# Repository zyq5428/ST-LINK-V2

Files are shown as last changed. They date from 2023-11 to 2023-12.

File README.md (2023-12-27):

# ST-LINK-V2
依据参考资料制作ST-LINK-V2，并实践一些Allegro技巧。

## 初衷

* 自己做一些ST-LINK便于后期自己调试STM32芯片
* 扩展一些UART，I2C，GPIO接口出来，其他时候作为一个STM32F103开发板用
* 重新熟悉下Allegro软件，并实践一些新版本的技巧
* 自己根据需要，亲自做里面用到的所有器件的封装和3D

## 产品效果图

### Nucleo版本

* 正面

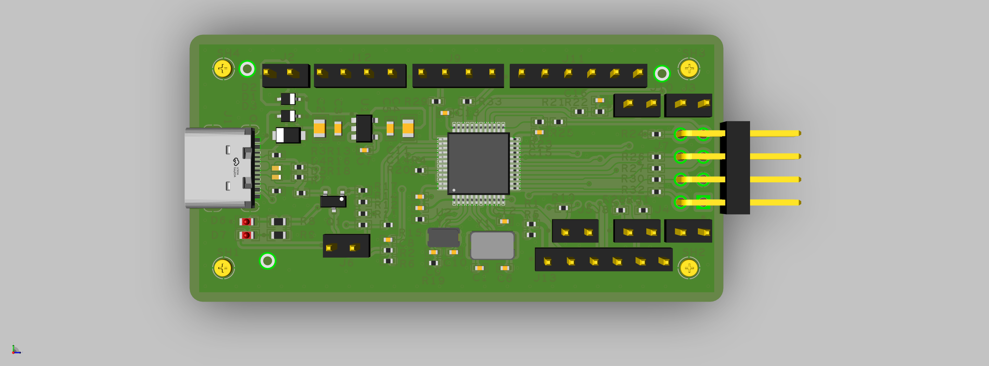
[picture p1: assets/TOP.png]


* 背面

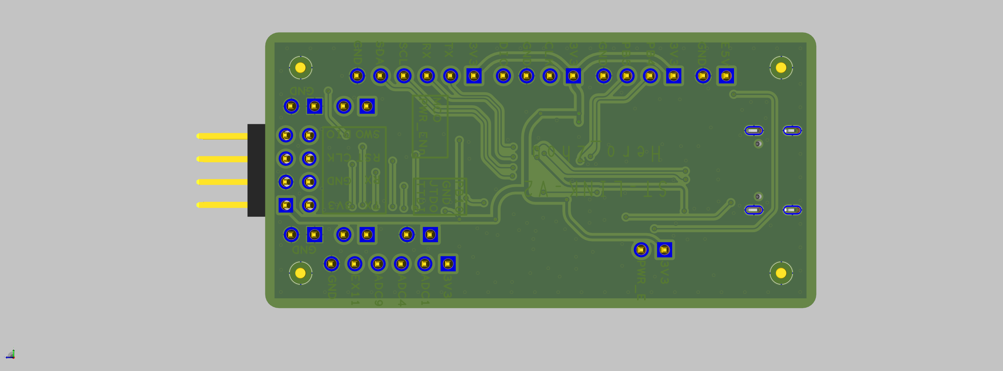
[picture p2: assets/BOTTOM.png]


* 为了方便以后可能用加热台自己贴片，所以尽量将元器件布置在同一面
* 为了最大化降低成本，采用双层板设计，但依旧尽力保证设计规范和美观

## 回板焊接

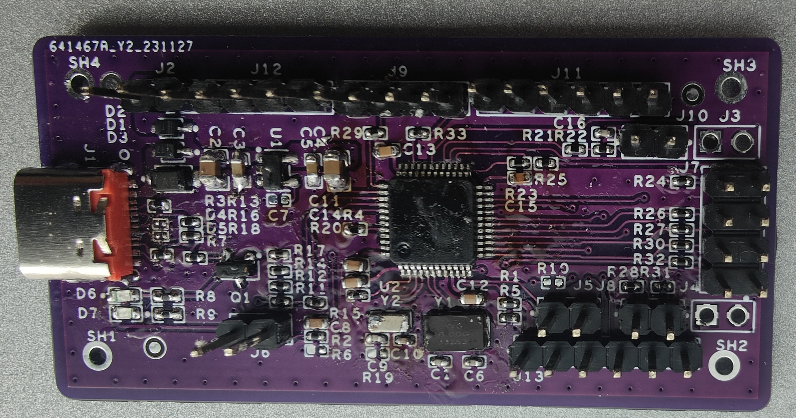
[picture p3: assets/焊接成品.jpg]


### 优化版

* 在Nucleo版本上进行了一些优化，去除了不必要的东西，然后按照自己的想法进行了一些接口的预留

* 正面

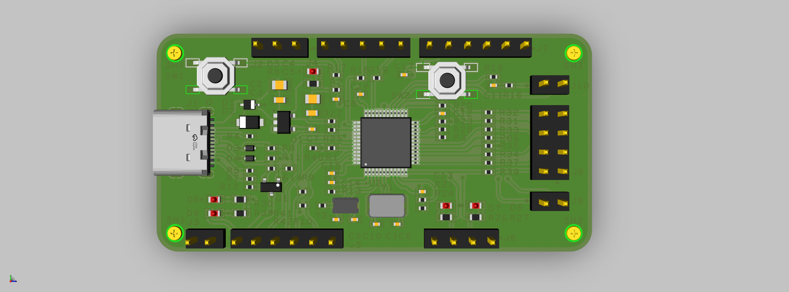
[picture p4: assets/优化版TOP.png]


* 背面

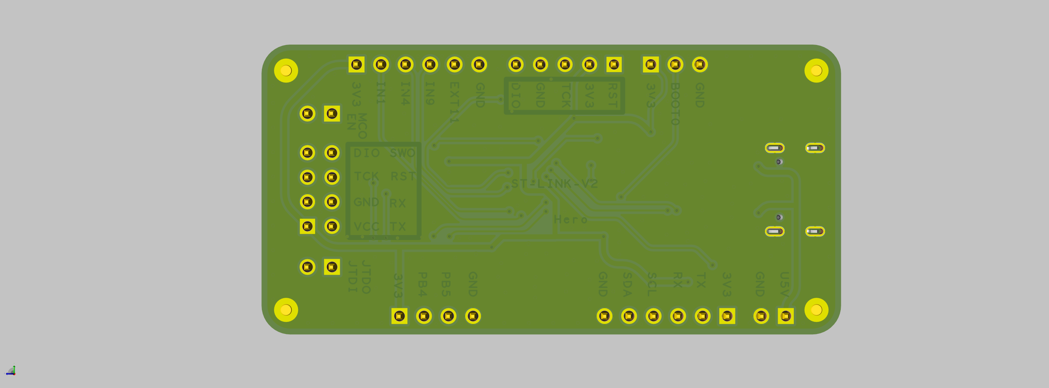
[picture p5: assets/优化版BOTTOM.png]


* 拼板效果图

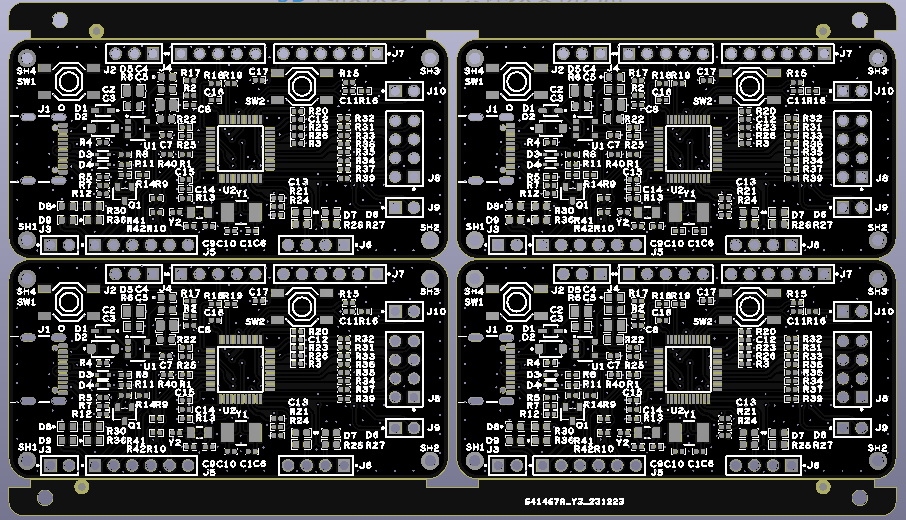
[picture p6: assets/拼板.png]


* PCB回板

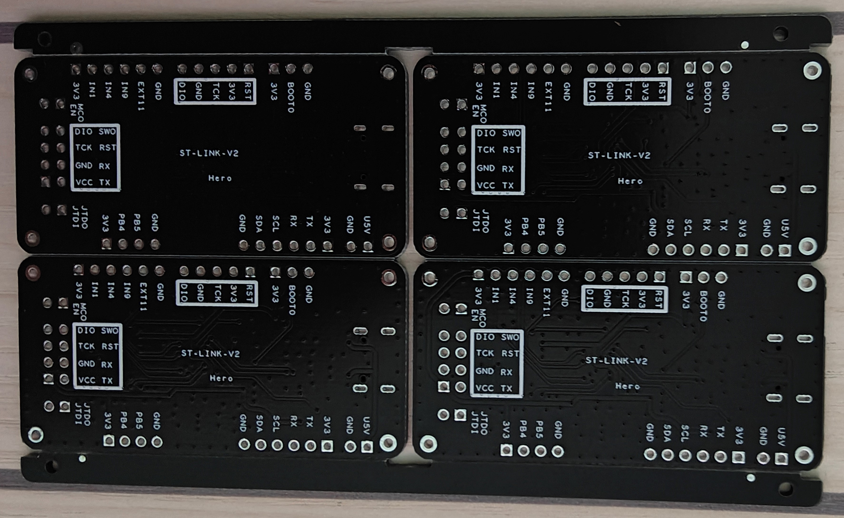
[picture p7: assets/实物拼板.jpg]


* 成品

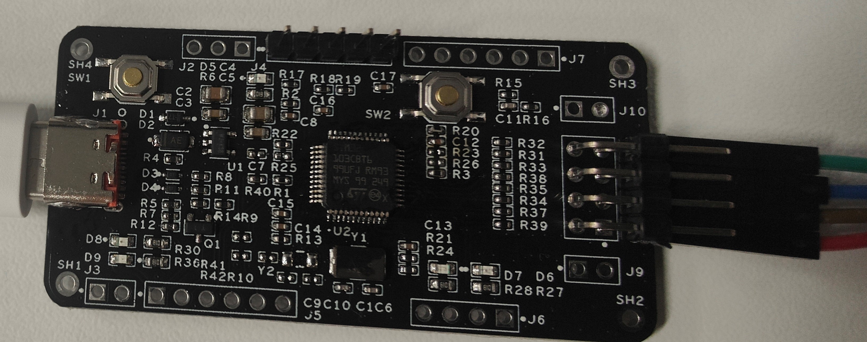
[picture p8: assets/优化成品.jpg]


## 原理介绍

借鉴于：https://oshwhub.com/CYIIOT/ST_LINK-V2_1

### 简介

* ST-Link的硬件，官方推出了三大版本：V1、V2和V3。在官方《TN1235 ST-LINK衍生产品概述》中有详细的说明。
* ST-Link/V2：支持STM32和STM8调试，不带虚拟串口，TB上卖的大多是这种，目前手头还有好几个这个版本的ST-Link。后面会使用这个版本进行烧录。
* ST-Link/V2-1：支持STM32调试，带虚拟串口和虚拟U盘下载，目前ST官方的Nucleo系列评估板上面板载的ST-Link就是这个版本。
* 潘多拉开发板上的ST-link V2-1 出厂主控使用的是FLASH 容量为64K的STM32F103C8T6，但是ST-link V2-1最新的固件已经超过了64K，芯片容量不足。 因此本项目主控选择的是FLASH容量为128KB的STM32F103CBT6（商品编号：C8304），这是C8T6的大容量版本，可以直接PIN to PIN 替换。也可以使用合宙通信推出的AIR32F103CBT6，有伙伴测试是OK的。
  * AIR32F103CBT6参考链接：[AIR32F103芯片 - LuatOS 文档](https://wiki.luatos.com/chips/air32f103/mcu.html)

### 版本检测和处理

* All ST-Link variants:
    * PC13/14 open -> Standalone ST-Link v2 or baite, some STM32 Disco w/o accessible UART RX/TX
    * PC13 low -> SWIM internal connection
    * PC13/PC14 both low -> ST-Link v2 on some F4_Diso boards.

### USB 枚举

* USB设备的电流是设备接入计算机的时候，枚举的过程中向计算机申请的，有一个8位寄存器，值范围是0~24，对应的电流是20mA~500mA。如果枚举过程中设备没有向计算机提交这个需要电流的值，计算机则默认按最大电流提供，USB2.0设备是500mA，USB1.1设备是200mA。

* 标准下行端口（SDP）
    * 这种端口的D+和D-线上具有15kΩ下拉电阻。限流值为：挂起时2.5mA，连接时为100mA，连接并配置为较高功率时为500mA。

* 根据USB协议，工作在主机模式，USB DP/DM下拉到GND，工作在设备模式，上拉到VCC（DP上拉表示高全速设备，DM上拉表示低速设备，STM32在Device模式只支持高速或全速）。
    * STM32F103的USB是全速的从设备，所以D+上需要一个1.5K的上拉电阻。建议用一个IO口控制这个上拉电阻，因为插入USB主机时，如果直接接这个上拉电阻，USB主机会直接枚举设备，如果STM32F103没有准备好则可能识别错误。如果用GPIO控制，可以保证STM32F103已经准备好了再枚举设备。

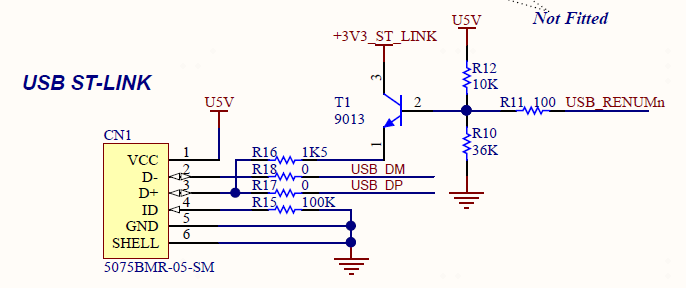
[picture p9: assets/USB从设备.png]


### 32.768KHz晶振

* 我的板子上预留了一个小封装的32.768KHz晶振，方便后期改为通用开发板功能。

### 电源

* 当ST-LINK的USB供电时：
    * ST-LINK使用一个3.3V 150mA LDO进行供电，供电电源为+3V3_ST_LINK。
    * 在USB枚举之前，只有ST-LINK部分供电，因为主机PC只能提供100mA电流。在USB枚举过程中，Nculeo板向主机PC请求300mA电流，如果主机可提供所需电流，则通过PWR_ENn拉低打开U5V供电MOS，这时目标MCU的3.3V LDO会输出3.3V电压，目标板开始供电。如果请求失败，则不打开U5V供电MOS。
    * PWR_EXT(PB3)作用：
        * 如果接ST_LINK的3.3V供电电源，则允许最大电流100mA，使用U5V供电的话，要连接,可以选择4.7K上拉；
        * 如果浮空，则允许最大电流300mA；

* E5V是外部7-12V的供电，通过一个5.0V 800mA的 LDO进行供电。

* AIN_1功能:
    * ST-LINK在烧录时，通过PWR_ENn拉低打开U5V供电MOS，这时目标MCU的3.3V LDO会输出3.3V电压。
    * AIN_1引脚通过上下各4.7K的分压电阻，判断MCU供电是否正常，如果只是做ST_LINK功能，直接接ST_LINK的3.3V供电电源。

### BOOT启动配置



* 一般来说就是指我们下好程序后，重启芯片时，SYSCLK的第4个上升沿，BOOT引脚的值将被锁存。用户可以通过设置BOOT1和BOOT0引脚的状态，来选择在复位后的启动模式。
    * 1、第一种方式(boot0 = 0)：Flash memory启动方式，启动地址：0x08000000 是STM32内置的Flash，一般我们使用JTAG或者SWD模式下载程序时，就是下载到这个里面，重启后也直接从这启动程序。基本上都是采用这种模式。
    * 2、第二种方式(boot0 = 1；boot1 = 0)：System memory启动方式，启动地址：0x1FFF0000从系统存储器启动，这种模式启动的程序功能是由厂家设置的。一般来说，这种启动方式用的比较少。系统存储器是芯片内部一块特定的区域，STM32在出厂时，由ST在这个区域内部预置了一段BootLoader， 也就是我们常说的ISP程序， 这是一块ROM，出厂后无法修改。一般来说，我们选用这种启动模式时，是为了从串口下载程序，因为在厂家提供的BootLoader 中，提供了串口下载程序的固件，可以通过这个BootLoader将程序下载到系统的Flash中。但是这个下载方式需要以下步骤：
        * 1、将BOOT0设置为1，BOOT1设置为0，然后按下复位键，这样才能从系统存储器启动BootLoader
        * 2、最后在BootLoader的帮助下，通过串口下载程序到Flash中
        * 3、程序下载完成后，又有需要将BOOT0设置为GND，手动复位，这样，STM32才可以从Flash中启动可以看到， 利用串口下载程序还是比较的麻烦，需要跳帽跳来跳去的，非常的不注重用户体验。
    * 3、第三种方式(boot0 = 1;boot1 = 1)：SRAM启动方式。，启动地址：0x20000000 内置SRAM，既然是SRAM，自然也就没有程序存储的能力了，这个模式一般用于程序调试。假如我只修改了代码中一个小小的 地方，然后就需要重新擦除整个Flash，比较的费时，可以考虑从这个模式启动代码（也就是STM32的内存中），用于快速的程序调试，等程序调试完成后，在将程序下载到SRAM中。
* 关于启动地址，理论上，CM3中规定上电后CPU是从0地址开始执行，但是这里中断向量表却被烧写在0x0800 0000地址里(Flash memory启动方式)，那启动时不就找不到中断向量表了？既然CM3定下的规矩是从0地址启动，SMT32当然不能破坏ARM定下的“规矩”，所以它做了一个启动映射的过程，就是和芯片上总能见到的BOOT0和BOOT1有关了，当选择从主Flash启动模式后，芯片一上电，Flash的0x0800 0000地址被映射到0地址处，不影响CM3内核的读取，所以这时的CM3既可以在0地址处访问中断向量表，也可以在0x0800 0000地址处访问中断向量表，而代码还是在0x0800 0000地址处存储的。
* 关于flash死锁的解决办法(Flash memory启动方式)，开发调试过程中，由于某种原因导致内部Flash锁死，无法连接SWD以及JTAG调试，无法读到设备，可以通过修改BOOT模式重新刷写代码。修改为BOOT0=1，BOOT1=0即可从系统存储器启动，ST出厂时自带Bootloader程序，SWD以及JTAG调试接口都是专用的。重新烧写程序后，可将BOOT模式重新更换到BOOT0=0，BOOT1=X即可正常使用。

* 我们可以通过10K或100K电阻接VCC或者GND，建议BOOT1接地，BOOT0预留一个3 Pin端子，以防后期芯片flash锁死了。

### PB10作用

* 暂时没搞懂，我看别人不接和接VCC，VDD都没有影响。

### COM指示灯

* 在ST官方的ST-Link V2.1图纸中有一个名为COM的指示灯,这是一个红绿双色的LED指示灯，就是下图所示的这个LED。

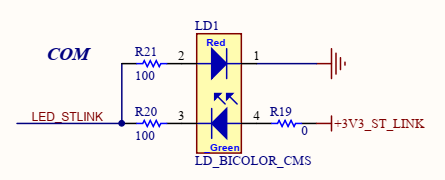
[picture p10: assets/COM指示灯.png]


* 那么这个指示灯有什么作用呢，在官方的TN1235技术手册中有专门的介绍，截取相关部分如下：

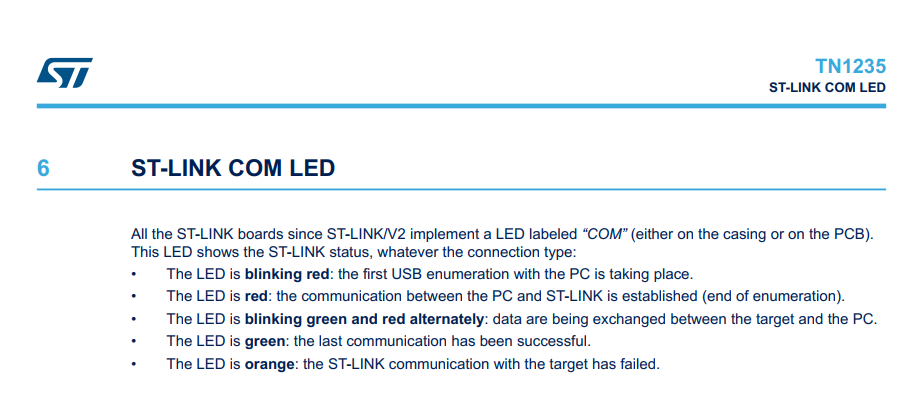
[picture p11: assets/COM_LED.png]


* 自ST-LINK/V2起，所有ST-LINK板均带有一个标有“COM”的LED（在外壳或PCB上）。无论连接类型如何，此LED都会显示ST-LINK状态：
    * LED呈红色闪烁：正在与PC进行第一个USB枚举。
    * LED为红色：PC与ST-LINK之间的通信已建立（枚举结束）。
    * LED呈绿色和红色交替闪烁：正在目标和PC之间交换数据。
    * LED为绿色：上一次通信已成功。
    * LED为橙色：与目标的ST-LINK通信失败

## 烧录固件

### 固件版本

* 由于官方没有将ST-Link里面源码公开，同时也没有直接给出ST-Link固件（读保护），但是目前（2020年7月）网上已有流传多个版本的固件。
    * 版本一：STLink V2.J16.S4版本固件：标准V2版本，支持SWD和SWIM接口，这个版本的固件是。
    * 版本二：STLink V2.J28.M18版本固件：是用于ST-LINK/V2-1、ST-LINK/V2-A、ST-LINK/V2-B板(具有STM32调试接口、大容量存储接口、虚拟COM端口)的版本。
    * 本项目制作ST-Link V2-1 必须使用V2.J28.M18这个版本作为烧录的固件版本。

### 烧录工具

* 第一次烧录固件可使用这两个工具：
    * STM32CubeProg
    * STM32 ST-LINK Utility
* 本次烧录使用STM32 ST-LINK Utility，STM32 ST-LINK Utility的功能比STM32CubeProg要稍微简单一些，其主要功能也是编程（下载）。烧录截图如下，操作很简单，大概看一下就知道了:

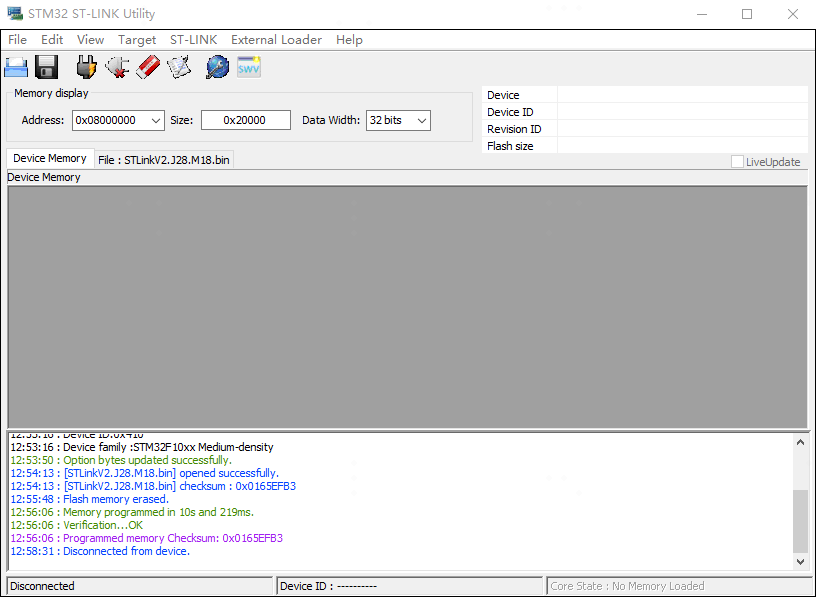
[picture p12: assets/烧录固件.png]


### 升级ST-LINK

* 固件更新有三种方法：
    * 官方固件升级应用程序ST-LinkUpgrade
    * 使用STM32CubeProg或者STM32 ST-LINK utility自带的升级工具升级
    * 使用Keil MDK-ARM 内置的升级工具进行升级，当ST-link 的版本低于MDK内置的版本时，会提示进行升级。Keil MDK-ARM v5.31内置固件升级版本与STM32CubeProg V2.4.0 内置固件升级版本是一样的。
* 本次升级使用ST-LinkUpgrade，升级截图如下：

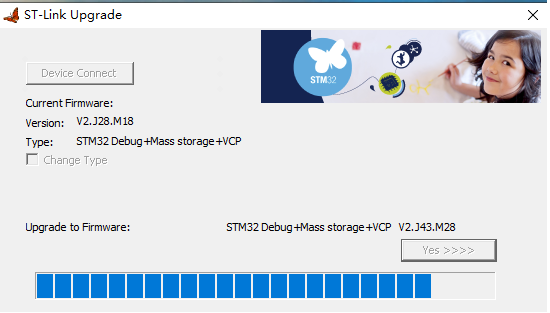
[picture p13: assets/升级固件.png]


* 至此，ST-LINK的制作就完成了。

## 注意事项

* ST-LINK 固件升级工具不知从哪个版本开始，不支持跨版本更新固件。
* ST-LINK 最近的几个版本的固件已加入了读保护，SWD口是锁上的，所以不能通过SWD口读写固件。
    * 如果想改为其他的，我们可以用STM32 ST-LINK utility将写保护的级别修改。菜单栏target里打开Option Bytes...选项，或者直接通过快捷键ctrl+B打开，请确保当前已经正确连接了stlink和目标板，否则会出现报错。
    * 关键点：将Read Out Protection选项设置为disable，点击Apply，这时候Flash已经成功解锁了。但是同时发现，内部Flash已经被擦除了；这可能STM32的保护机制有关，防止程序被拷机，然后进行反编译破解，这样也可以提高破解的门槛。
    * 完成以上步骤之后，在菜单栏Target下选择Disconnect，或者通过快捷键ctrl+D断开和目标板的连接；重新进入MDK，就能正常对目标板进行调试，仿真，以及程序的烧写。

正确连接的情况下，打开Option Bytes...，发现在这里Read Out Protection选项是enable，这个表示无法通过swd读取STM32内部Flash的程序。
    
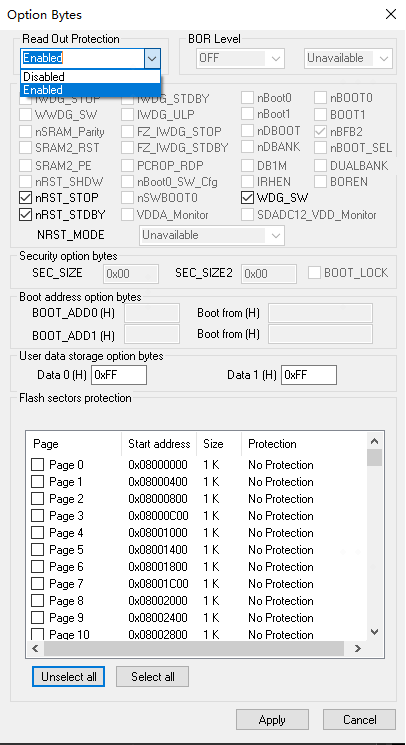
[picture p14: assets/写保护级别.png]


* 如果想改成DAP-LINK 之类的固件，不能通过SWD口烧录固件，但是可以通过ISP的方式擦除STM32的固件信息，然后就可以使用SWD口正常读写。
    * USB转串口连接线烧写（又称ISP烧写，且使用的串口必须是串口1）:
        * Step1:将BOOT0设置为1，BOOT1设置为0，然后按下复位键，这样才能从系统存储器启动BootLoader;
        * Step2:最后在BootLoader的帮助下，通过串口下载程序到Flash中;
        * Step3:程序下载完成后，必须要将BOOT0设置为GND，手动复位，这样，STM32才可以从Flash中启动。

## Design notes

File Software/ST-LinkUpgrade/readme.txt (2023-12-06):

STLink firmware upgrade applications

1. In folder Windows:

   Contains the application in its "historical" form: executable dedicated to Windows + dll.
   With all most recent firmwares (V1J13S3 for ST-Link/V1 boards, V2J43S7 for ST-Link/V2 boards,
   V2J43M28 for ST-Link/V2-1 boards, V3J13M4 for STLINK-V3 boards, V4J3B1P4 for STLINK-V3PWR)

2. In folder AllPlatforms:

   Contains a new GUI based on Java, with native ST-Link libraries for running on Windows 32 bits,
   Windows 64bits, Linux 32bits, Linux 64bits and MacOS 64bits.
   
   The application requires the Java Runtime Environment 7u51 (or more recent) being installed.
   In platforms without .jar file extension association, the application can be launch by the command
   "java -jar STLinkUpgrade.jar".

   On Linux, the application relies on libusb-1.0, which must be installed separately. For
   instance on Ubuntu, through the command "sudo apt-get install libusb-1.0".

   On Linux, users must be granted with rights for accessing the ST-Link USB devices. To do
   that, it might be necessary to add rules into /etc/udev/rules.d. This can be achieved by
   running one of the package provided into the subdirectory StlinkRulesFilesForLinux.

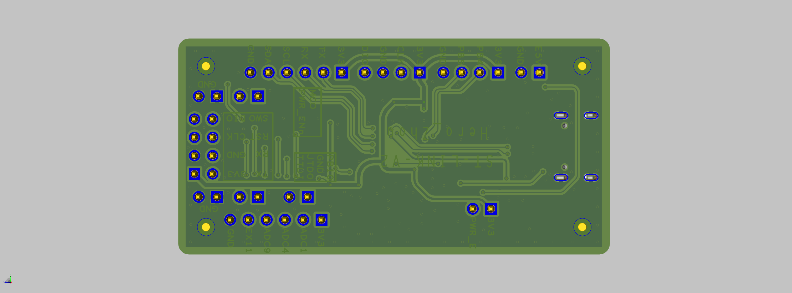
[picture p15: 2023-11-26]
Hardware/Original/allegro/ASM/BOTTOM.png

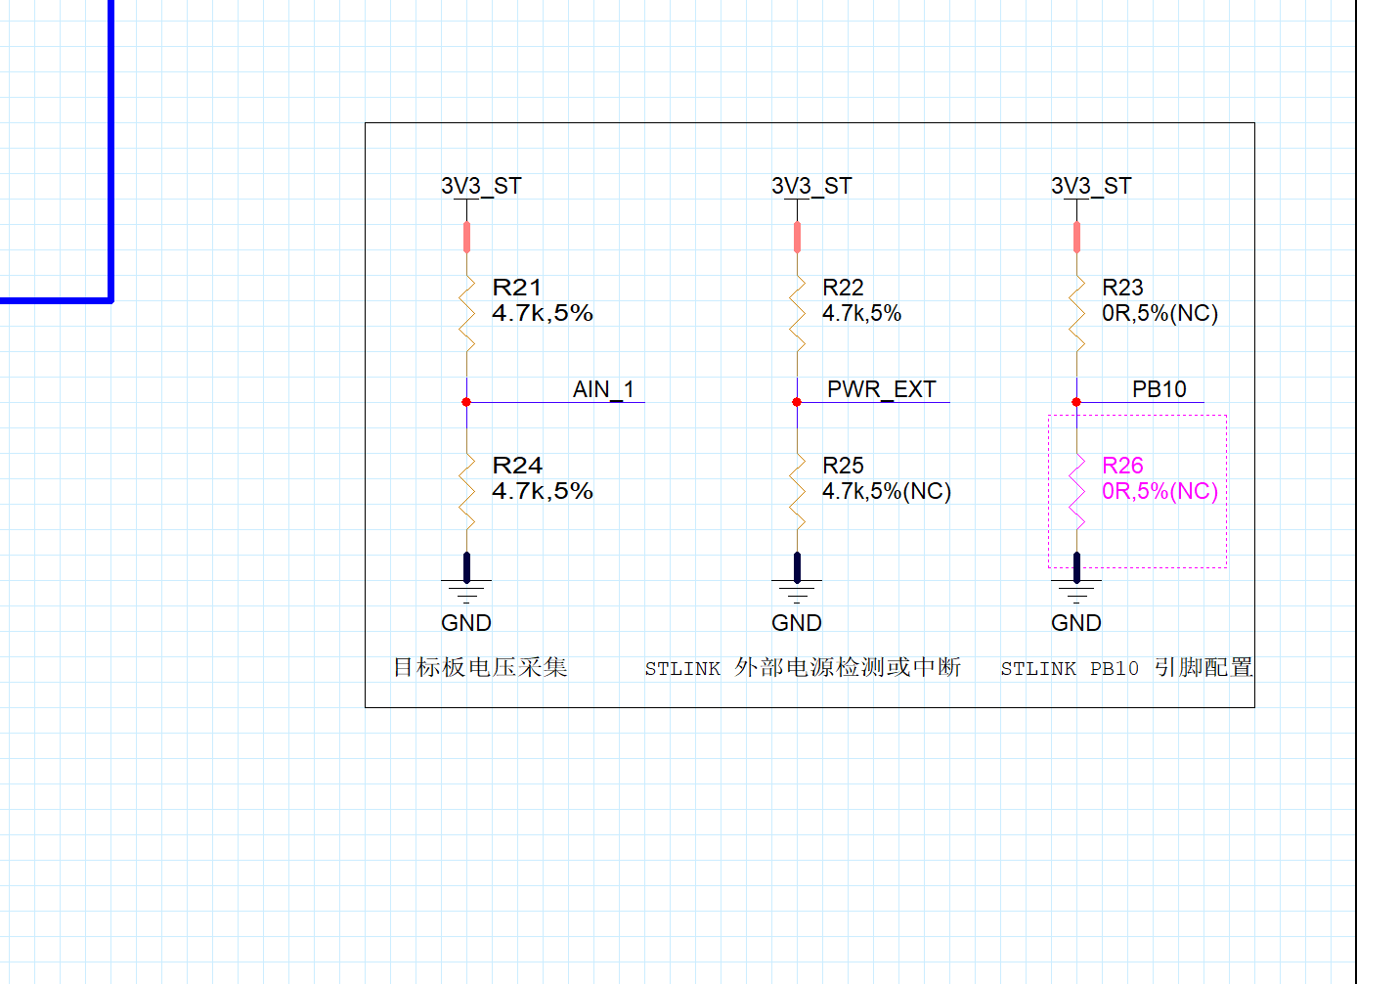
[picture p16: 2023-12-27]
Hardware/Optimize/ST-LINK-V2_PRO_OPT.png

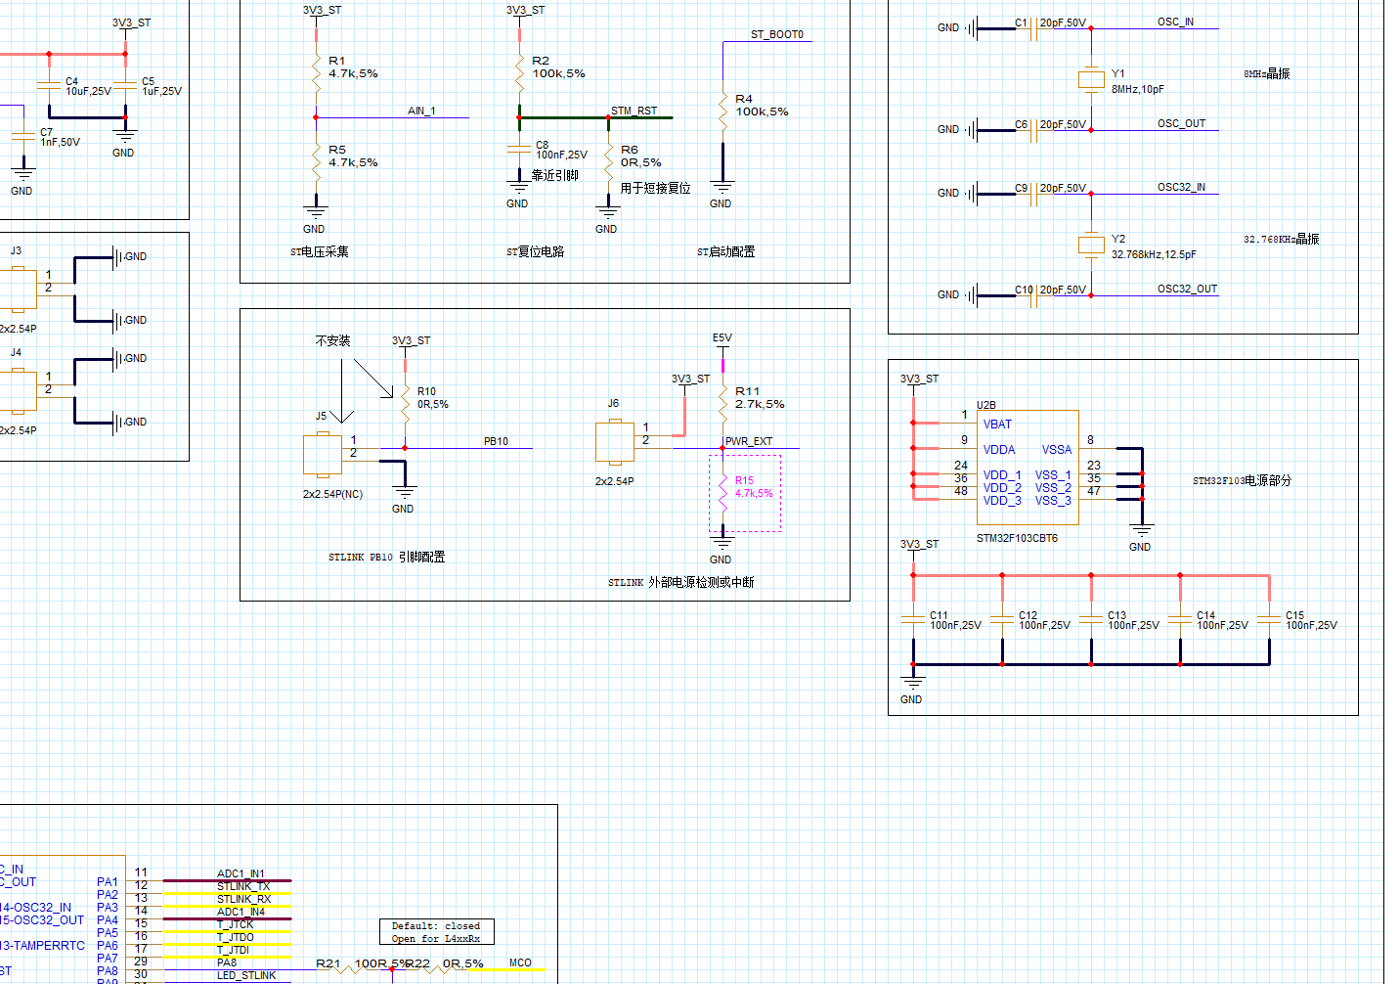
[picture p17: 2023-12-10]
Hardware/Original/ST-LINK-V2_PRO.png

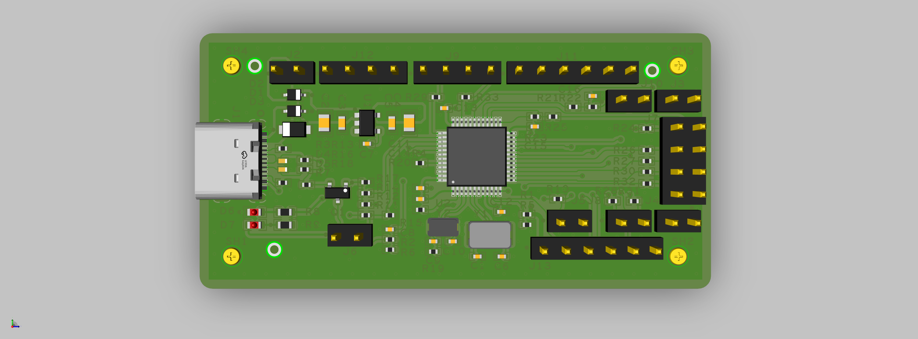
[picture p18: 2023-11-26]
Hardware/Original/allegro/ASM/TOP.png

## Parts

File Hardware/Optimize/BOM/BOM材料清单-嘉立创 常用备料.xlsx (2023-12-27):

xxxx项目物料清单
型号 | 封装 | 参数/规格 | 品牌 | 分类 | 单套用量 | 商品编号
 | C0402 | 100nF,25V |  | 贴片电容 | 100 | C56392 | 0
 | SOD-523 | TVSS5VCES-02GP-J |  | 静电放电(ESD)保护器件 | 50 | C5199217
 | LED0603 | Red_LED |  | 发光二极管/LED | 50 | C84263 | 20
 | LED0603 | Green_LED |  | 发光二极管/LED | 50 | C84267 | 20
 | LED0603 | Blue_LED |  | 发光二极管/LED | 50 | C84266 | 20
 | USB-C-SMD-16P | TYPE-C-16P |  | USB连接器 | 20 | C2997434 | 5
 | R0402 | 0R,5% |  | 贴片电阻 | 300 | C17168 | 100
 | SW_SMD_4P_5D1x5D1 | TS-1187A-B-A-B |  | 轻触开关 | 50 | C318884
 | SOT23-5 | RT9013-33GB |  | 线性稳压器(LDO) | 20 | C587158 | 5
 | LQFP48 | STM32F103CBT6 |  | 单片机 | 2 | C8304 | 5
 | SMD5032-2P | 8MHz,10pF |  | 无源晶振 | 20 | C115962 | 5
 | SMD3215-2P | 32.768kHz,12.5pF |  | 无源晶振 | 10 | C620155 | 5
 | SOT-23-5 | PJ4054B |  | 电池管理 | 20 | C2911335
 | SOP-8 | CH340N |  | USB芯片 | 20 | C2977777
 | 插件,D=9mm | HNB09A05 |  | 蜂鸣器 | 20 | C96493

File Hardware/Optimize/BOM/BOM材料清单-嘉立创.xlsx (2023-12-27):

xxxx项目物料清单
型号 | 封装 | 参数/规格 | 品牌 | 分类 | 单套用量 | 商品编号
 | C0402 | 20pF,50V |  | 贴片电容 | 5 | C1554 | 100
 | C0805 | 10uF,25V |  | 贴片电容 | 2 | C15850 | 50
 | C0603 | 1uF,25V |  | 贴片电容 | 2 | C15849 | 100
 | C0402 | 100nF,25V |  | 贴片电容 | 7 | C56392 | 0
 | C0402 | 1N4007WS |  | 通用二极管 | 1 | C7473299 | 50
 | SOD-323 | SMF5.0A |  | 瞬态抑制二极管(TVS) | 1 | C908213 | 20
 | SOD-523 | TVSS5VCES-02GP-J |  | 静电放电(ESD)保护器件 | 2 | C5199217
 | LED0603 | Red_LED |  | 发光二极管/LED | 3 | C84263 | 20
 | LED0603 | Green_LED |  | 发光二极管/LED | 2 | C84267 | 20
 | USB-C-SMD-16P | TYPE-C-16P |  | USB连接器 | 1 | C2997434 | 5
 | HEADER_4X2_2P54 | 4x2.54P |  | 排针 | 1 | C492429 | 5
 | HEADER_6X1_2P54 | 6x2.54P |  | 排针 | 1 | C2895846 | 5
 | SOT-23 | SS8050 |  | 三极管(BJT) | 1 | C2150 | 50
 | R0402 | 100k,5% |  | 贴片电阻 | 2 | C25741 | 100
 | R0402 | 0R,5% |  | 贴片电阻 | 16 | C17168 | 100
 | R0402 | 5.1k,5% |  | 贴片电阻 | 2 | C25905 | 100
 | R0603 | 1k,5% |  | 贴片电阻 | 5 | C21190 | 100
 | R0402 | 10k,5% |  | 贴片电阻 | 2 | C60490 | 100
 | R0402 | 100R,5% |  | 贴片电阻 | 3 | C25076 | 100
 | R0402 | 36k,5% |  | 贴片电阻 | 1 | C43676 | 100
 | R0402 | 1.5k,5% |  | 贴片电阻 | 1 | C25867 | 100
 | R0402 | 4.7k,5% |  | 贴片电阻 | 3 | C25900 | 100
 | SW_SMD_4P_5D1x5D1 | TS-1187A-B-A-B |  | 轻触开关 | 2 | C318884
 | SOT23-5 | RT9013-33GB |  | 线性稳压器(LDO) | 1 | C587158 | 5
 | LQFP48 | STM32F103CBT6 |  | 单片机 | 1 | C8304 | 5
 | SMD5032-2P | 8MHz,10pF |  | 无源晶振 | 1 | C115962 | 5
 | SMD3215-2P | 32.768kHz,12.5pF |  | 无源晶振 | 1 | C620155 | 5

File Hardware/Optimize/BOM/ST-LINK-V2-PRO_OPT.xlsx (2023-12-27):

Item | Quantity | Reference | Part | PCB Footprint
1 | 5 | C1,C6,C9,C10,C11 | 20pF,50V | CAPC100X50X55L25N
2 | 2 | C2,C4 | 10uF,25V | CAPC200X125X145L45N
3 | 2 | C3,C5 | 1uF,25V | CAPC160X80X90L30N
5 | 7 | C8,C12,C13,C14,C15,C16,C17 | 100nF,25V | CAPC100X50X55L25N
6 | 1 | D1 | 1N4007WS | SOD265X130X110L32X32N
7 | 1 | D2 | SMF5.0A | SODFL370X180X135L60_50X100N
8 | 2 | D3,D4 | TVSS5VCES-02GP-J | SODFL160X80X70L20X30N
9 | 3 | D5,D6,D8 | Red_LED | LEDC160X80X70L30N
10 | 2 | D7,D9 | Green_LED | LEDC160X80X70L30N
11 | 1 | J1 | TYPE-C-16P | USB-C-SMD-16P
12 | 1 | J2 | 4x2.54P | HEADER_3X1_2P54
13 | 3 | J3,J9,J10 | 2x2.54P | HEADER_2X1_2P54
14 | 1 | J4 | 5x2.54P | HDRV5W64P254_5X1_1270X254H860
15 | 2 | J5,J7 | 6x2.54P | HEADER_6X1_2P54
16 | 1 | J6 | 4x2.54P | HEADER_4X1_2P54
17 | 1 | J8 | P2.54x4x2 | HDRV8W64P254_4X2_1016X502H838
18 | 1 | Q1 | SS8050 | SOT23-3P95_240X110L53X44N
19 | 2 | R1,R2 | 100k,5% | RESC100X50X40L25N
20 | 16 | R3,R8,R11,R16,R17,R18,R19,R31,R32,R33,R34,R35,R37,R38,R39,R40 | 0R,5% | RESC100X50X40L25N
21 | 2 | R4,R5 | 5.1k,5% | RESC100X50X40L25N
22 | 5 | R6,R27,R28,R30,R36 | 1k,5% | RESC160X80X55L30N
23 | 2 | R7,R13 | 10k,5% | RESC100X50X40L25N
24 | 3 | R9,R15,R20 | 100R,5% | RESC100X50X40L25N
26 | 1 | R12 | 36k,5% | RESC100X50X40L25N
27 | 1 | R14 | 1.5k,5% | RESC100X50X40L25N
28 | 3 | R21,R22,R24 | 4.7k,5% | RESC100X50X40L25N
32 | 2 | SW1,SW2 | TS-1187A-B-A-B | SW_SMD_4P_5D1x5D1
33 | 1 | U1 | RT9013-33GB | SOT23-5
34 | 1 | U2 | STM32F103CBT6 | QFP50P900X900X145-48N
35 | 1 | Y1 | 8MHz,10pF | SMD5032-2P
36 | 1 | Y2 | 32.768kHz,12.5pF | SMD3215-2P

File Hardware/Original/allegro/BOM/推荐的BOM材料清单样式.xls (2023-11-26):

Comment型号 | Designator位号 | Footprint封装 | 嘉立创元件编号(可不要此列)
100uF | C1 | CASE-B_3528 | C16133
100nF | C2, C9 C10 位号与位号之间仅支持逗号或空格分隔, 不支持其他符号 | 0603 | C14663
300KΩ | R4, R7 位号与位号之间使用其他符号 分隔 (、：. \ | 等)，出事故那是必然现象。 漏贴,错贴那是肯定会出现 | 0603 | C23024
15KΩ | R5, R6 | 0603_R | C22809
100KΩ | R1, R3 | 0603_R | C25803
10uF | C3-5 区间表达法,仅支持 C3-5 这种样式, 这种样式代表C3,C4,C5 | 1206_C | C13585
100Ω | R2 | 0603_R | C22775
1N4148WS | D1 绝对不能在这一列写备注, 千万别在这里写备注, 写备注一定会翻车 | SOD-323 | C2128
LM358DR2G | U1 | SOIC-8_150mil | C7950
HT7550-1 | VR1 | SOT-89(SOT-89-3) | C16106
使用前，请删除所有中文说明
使用前，请删除所有中文说明
使用前，请删除所有中文说明

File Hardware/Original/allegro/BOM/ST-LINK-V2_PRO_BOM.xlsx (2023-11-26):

Item | Quantity | Reference | Part | PCB Footprint
1 | 5 | C1,C6,C9,C10,C16 | 20pF,50V | CAPC100X50X55L25N
2 | 2 | C2,C4 | 10uF,25V | CAPC200X125X145L45N
3 | 2 | C3,C5 | 1uF,25V | CAPC160X80X90L30N
4 | 1 | C7 | 1nF,50V | CAPC100X50X55L25N
5 | 6 | C8,C11,C12,C13,C14,C15 | 100nF,25V | CAPC100X50X55L25N
6 | 2 | D1,D2 | 1N4007WS | SOD265X130X110L32X32N
7 | 1 | D3 | SMF5.0A | SODFL370X180X135L60_50X100N
8 | 2 | D4,D5 | KLXES15AAA1 | DIONDFN2_100X50X40L32X37N
9 | 1 | D6 | Red_LED | LEDC160X80X70L30N
10 | 1 | D7 | Green_LED | LEDC160X80X70L30N
11 | 1 | J1 | TYPE-C-16P | USB-C-SMD-16P
12 | 6 | J2,J3,J4,J6,J8,J10 | 2x2.54P | HEADER_2X1_2P54
13 | 1 | J5 | 2x2.54P(NC) | HEADER_2X1_2P54
14 | 1 | J7 | P2.54x4x2 | HDRV8W64P254_4X2_1016X502H838
15 | 2 | J9,J12 | 4x2.54P | HEADER_4X1_2P54
16 | 2 | J11,J13 | 6x2.54P | HEADER_6X1_2P54
17 | 1 | Q1 | SS8050 | SOT23-3P95_240X110L53X44N
18 | 3 | R1,R5,R15 | 4.7k,5% | RESC100X50X40L25N
19 | 2 | R2,R4 | 100k,5% | RESC100X50X40L25N
20 | 2 | R3,R7 | 5.1k,5% | RESC100X50X40L25N
21 | 7 | R6,R10,R13,R16,R22,R29,R33 | 0R,5% | RESC100X50X40L25N
22 | 2 | R8,R9 | 1k,5% | RESC160X80X55L30N
23 | 1 | R11 | 2.7k,5% | RESC100X50X40L25N
24 | 3 | R12,R19,R20 | 10k,5% | RESC100X50X40L25N
25 | 3 | R14,R21,R23 | 100R,5% | RESC100X50X40L25N
26 | 1 | R17 | 36k,5% | RESC100X50X40L25N
27 | 1 | R18 | 1.5k,5% | RESC100X50X40L25N
28 | 8 | R24,R25,R26,R27,R28,R30,R31,R32 | 22R,5% | RESC100X50X40L25N
29 | 4 | SH1,SH2,SH3,SH4 | Screw_Hole_M1.2 | MTGP240H140
30 | 1 | U1 | RT9013-33GB | SOT23-5
31 | 1 | U2 | STM32F103CBT6 | QFP50P900X900X145-48N
32 | 1 | Y1 | 8MHz,10pF | SMD5032-2P
33 | 1 | Y2 | 32.768kHz,12.5pF | SMD3215-2P

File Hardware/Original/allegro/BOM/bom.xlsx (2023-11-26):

Value | Description 1 | Description 2 | Footprint | Quantity | Designator | Partnumber 1 | Manufacturer
0.05ohm 100MHz 2.5A |  |  | 805 | 1 | L1 | BLM21SP471SN1D
 |  |  |  |  |  |  |  | value 元器件的规格值
 |  |  |  |  |  |  |  | Description 1 描述1
 |  |  |  |  |  |  |  | Description 2 描述2
 |  |  |  |  |  |  |  | Footprint 封装信息
 |  |  |  |  |  |  |  | Quantity 元器件位号数量
 |  |  |  |  |  |  |  | Designator 位号
 |  |  |  |  |  |  |  | Partnumber 1 制造商料号
 |  |  |  |  |  |  |  | Manufacturer 制造商

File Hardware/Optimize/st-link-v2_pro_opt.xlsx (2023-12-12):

Item | Quantity | Reference | Part | PCB Footprint
1 | 5 | C1,C6,C9,C10,C16 | 20pF,50V | CAPC100X50X55L25N
2 | 2 | C2,C4 | 10uF,25V | CAPC200X125X145L45N
3 | 2 | C3,C5 | 1uF,25V | CAPC160X80X90L30N
4 | 1 | C7 | 1nF,50V | CAPC100X50X55L25N
5 | 7 | C8,C11,C12,C13,C14,C15,C17 | 100nF,25V | CAPC100X50X55L25N
6 | 1 | D2 | 1N4007WS | SOD265X130X110L32X32N
7 | 1 | D3 | SMF5.0A | SODFL370X180X135L60_50X100N
8 | 3 | D6,D10,D11 | Red_LED | LEDC160X80X70L30N
9 | 2 | D7,D12 | Green_LED | LEDC160X80X70L30N
10 | 2 | D8,D9 | TVSS5VCES-02GP-J | SODFL160X80X70L20X30N
11 | 1 | J1 | TYPE-C-16P | USB-C-SMD-16P
12 | 3 | J2,J8,J10 | 2x2.54P | HEADER_2X1_2P54
13 | 1 | J7 | P2.54x4x2 | HDRV8W64P254_4X2_1016X502H838
14 | 2 | J11,J13 | 6x2.54P | HEADER_6X1_2P54
15 | 1 | J12 | 4x2.54P | HEADER_4X1_2P54
16 | 1 | J15 | 5x2.54P | HDRV5W64P254_5X1_1270X254H860
17 | 1 | J17 | 4x2.54P | HEADER_3X1_2P54
18 | 1 | Q1 | SS8050 | SOT23-3P95_240X110L53X44N
19 | 3 | R1,R5,R36 | 4.7k,5% | RESC100X50X40L25N
20 | 2 | R2,R4 | 100k,5% | RESC100X50X40L25N
21 | 2 | R3,R7 | 5.1k,5% | RESC100X50X40L25N
22 | 5 | R8,R9,R38,R39,R40 | 1k,5% | RESC160X80X55L30N
23 | 2 | R10,R35 | 0R,5%(NC) | RESC100X50X40L25N
24 | 2 | R12,R20 | 10k,5% | RESC100X50X40L25N
25 | 16 | R13,R16,R22,R29,R33,R34,R37,R41,R42,R43,R44,R45,R46,R47,R48,R49 | 0R,5% | RESC100X50X40L25N
26 | 3 | R14,R21,R23 | 100R,5% | RESC100X50X40L25N
27 | 1 | R15 | 4.7k,5%(NC) | RESC100X50X40L25N
28 | 1 | R17 | 36k,5% | RESC100X50X40L25N
29 | 1 | R18 | 1.5k,5% | RESC100X50X40L25N
30 | 1 | R19 | 10k,5%(NC) | RESC100X50X40L25N
31 | 4 | SH1,SH2,SH3,SH4 | Screw_Hole_M1.2 | MTGP240H140
32 | 2 | SW1,SW3 | TS-1187A-B-A-B | SW_SMD_4P_5D1x5D1
33 | 1 | U1 | RT9013-33GB | SOT23-5
34 | 1 | U3 | STM32F103CBT6 | QFP50P900X900X145-48N
35 | 1 | Y1 | 8MHz,10pF | SMD5032-2P
36 | 1 | Y2 | 32.768kHz,12.5pF | SMD3215-2P

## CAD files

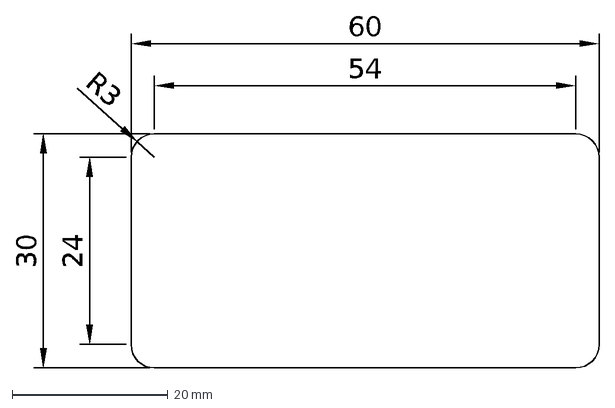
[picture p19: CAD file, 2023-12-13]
2D/ST-LINK-V2-1.dxf
54
24
R3
60
30

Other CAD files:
2D/ST-LINK-V2-1.dwg

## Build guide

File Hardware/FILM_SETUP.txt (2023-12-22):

axlFilmCreate( "OUTLINE" ?negative nil ?undefineLineWidth 6.00 ?sequence 15 
	?rotation 0 ?xOffset 0.00 ?yOffset 0.00 ?shapeBoundingBox 100.00 ?mirrored nil ?fullContact nil 
	?suppressUnconnectPads nil ?drawMissingPadApertures nil ?useApertureRotation nil 
	?suppressShapeFill nil ?vectorBasedPad t ?drawHolesOnly nil 
	?domains '(ipc2581 pdf artwork visibility ) ?ipc2581 '() 
	?layers '("BOARD GEOMETRY/DIMENSION" "BOARD GEOMETRY/DESIGN_OUTLINE" ))
axlFilmCreate( "ASSEMBLY_BOTTOM" ?negative nil ?undefineLineWidth 0.00 ?sequence 14 
	?rotation 0 ?xOffset 0.00 ?yOffset 0.00 ?shapeBoundingBox 100.00 ?mirrored nil ?fullContact nil 
	?suppressUnconnectPads nil ?drawMissingPadApertures nil ?useApertureRotation nil 
	?suppressShapeFill nil ?vectorBasedPad t ?drawHolesOnly nil 
	?domains '(ipc2581 pdf artwork visibility ) ?ipc2581 '() 
	?layers '("BOARD GEOMETRY/BOTTOM_ROOM" "BOARD GEOMETRY/BOTH_ROOMS" "REF DES/ASSEMBLY_BOTTOM" "PACKAGE GEOMETRY/ASSEMBLY_BOTTOM" "BOARD GEOMETRY/DESIGN_OUTLINE" ))
axlFilmCreate( "ASSEMBLY_TOP" ?negative nil ?undefineLineWidth 0.00 ?sequence 13 
	?rotation 0 ?xOffset 0.00 ?yOffset 0.00 ?shapeBoundingBox 100.00 ?mirrored nil ?fullContact nil 
	?suppressUnconnectPads nil ?drawMissingPadApertures nil ?useApertureRotation nil 
	?suppressShapeFill nil ?vectorBasedPad t ?drawHolesOnly nil 
	?domains '(ipc2581 pdf artwork visibility ) ?ipc2581 '() 
	?layers '("BOARD GEOMETRY/TOP_ROOM" "BOARD GEOMETRY/BOTH_ROOMS" "REF DES/ASSEMBLY_TOP" "PACKAGE GEOMETRY/ASSEMBLY_TOP" "BOARD GEOMETRY/DESIGN_OUTLINE" ))
axlFilmCreate( "PDF_A_BOTTOM" ?negative nil ?undefineLineWidth 0.00 ?sequence 12 
	?rotation 0 ?xOffset 0.00 ?yOffset 0.00 ?shapeBoundingBox 100.00 ?mirrored nil ?fullContact nil 
	?suppressUnconnectPads nil ?drawMissingPadApertures nil ?useApertureRotation nil 
	?suppressShapeFill nil ?vectorBasedPad t ?drawHolesOnly nil 
	?domains '(ipc2581 pdf artwork visibility ) ?ipc2581 '() 
	?layers '("REF DES/SILKSCREEN_BOTTOM" "PIN/BOTTOM" "PACKAGE GEOMETRY/SILKSCREEN_BOTTOM" "BOARD GEOMETRY/SILKSCREEN_BOTTOM" "BOARD GEOMETRY/DESIGN_OUTLINE" ))
axlFilmCreate( "PDF_A_TOP" ?negative nil ?undefineLineWidth 0.00 ?sequence 11 
	?rotation 0 ?xOffset 0.00 ?yOffset 0.00 ?shapeBoundingBox 100.00 ?mirrored nil ?fullContact nil 
	?suppressUnconnectPads nil ?drawMissingPadApertures nil ?useApertureRotation nil 
	?suppressShapeFill nil ?vectorBasedPad t ?drawHolesOnly nil 
	?domains '(ipc2581 pdf artwork visibility ) ?ipc2581 '() 
	?layers '("REF DES/SILKSCREEN_TOP" "PIN/TOP" "PACKAGE GEOMETRY/SILKSCREEN_TOP" "BOARD GEOMETRY/SILKSCREEN_TOP" "BOARD GEOMETRY/DESIGN_OUTLINE" ))
axlFilmCreate( "DRILL" ?negative nil ?undefineLineWidth 6.00 ?sequence 9 
	?rotation 0 ?xOffset 0.00 ?yOffset 0.00 ?shapeBoundingBox 100.00 ?mirrored nil ?fullContact nil 
	?suppressUnconnectPads nil ?drawMissingPadApertures nil ?useApertureRotation nil 
	?suppressShapeFill nil ?vectorBasedPad t ?drawHolesOnly nil 
	?domains '(ipc2581 pdf artwork visibility ) ?ipc2581 '() 
	?layers '("MANUFACTURING/PHOTOPLOT_OUTLINE" "MANUFACTURING/NCDRILL_LEGEND" "MANUFACTURING/NCDRILL_FIGURE" "MANUFACTURING/NCLEGEND-1-2" "BOARD GEOMETRY/DIMENSION" "BOARD GEOMETRY/DESIGN_OUTLINE" ))
axlFilmCreate( "SILKSCREEN_BOTTOM" ?negative nil ?undefineLineWidth 6.00 ?sequence 8 
	?rotation 0 ?xOffset 0.00 ?yOffset 0.00 ?shapeBoundingBox 100.00 ?mirrored nil ?fullContact nil 
	?suppressUnconnectPads nil ?drawMissingPadApertures nil ?useApertureRotation nil 
	?suppressShapeFill nil ?vectorBasedPad t ?drawHolesOnly nil 
	?domains '(ipc2581 pdf artwork visibility ) ?ipc2581 '() 
	?layers '("REF DES/SILKSCREEN_BOTTOM" "PACKAGE GEOMETRY/SILKSCREEN_BOTTOM" "BOARD GEOMETRY/SILKSCREEN_BOTTOM" "BOARD GEOMETRY/DESIGN_OUTLINE" ))
axlFilmCreate( "SILKSCREEN_TOP" ?negative nil ?undefineLineWidth 6.00 ?sequence 7 
	?rotation 0 ?xOffset 0.00 ?yOffset 0.00 ?shapeBoundingBox 100.00 ?mirrored nil ?fullContact nil 
	?suppressUnconnectPads nil ?drawMissingPadApertures nil ?useApertureRotation nil 
	?suppressShapeFill nil ?vectorBasedPad t ?drawHolesOnly nil 
	?domains '(ipc2581 pdf artwork visibility ) ?ipc2581 '() 
	?layers '("REF DES/SILKSCREEN_TOP" "PACKAGE GEOMETRY/SILKSCREEN_TOP" "BOARD GEOMETRY/SILKSCREEN_TOP" "BOARD GEOMETRY/DESIGN_OUTLINE" ))
axlFilmCreate( "SOLDERMASK_BOTTOM" ?negative nil ?undefineLineWidth 6.00 ?sequence 6 
	?rotation 0 ?xOffset 0.00 ?yOffset 0.00 ?shapeBoundingBox 100.00 ?mirrored nil ?fullContact nil 
	?suppressUnconnectPads nil ?drawMissingPadApertures nil ?useApertureRotation nil 
	?suppressShapeFill nil ?vectorBasedPad t ?drawHolesOnly nil 
	?domains '(ipc2581 pdf artwork visibility ) ?ipc2581 '() 
	?layers '("VIA CLASS/SOLDERMASK_BOTTOM" "PIN/SOLDERMASK_BOTTOM" "PACKAGE GEOMETRY/SOLDERMASK_BOTTOM" "BOARD GEOMETRY/SOLDERMASK_BOTTOM" "BOARD GEOMETRY/DESIGN_OUTLINE" ))
axlFilmCreate( "SOLDERMASK_TOP" ?negative nil ?undefineLineWidth 6.00 ?sequence 5 
	?rotation 0 ?xOffset 0.00 ?yOffset 0.00 ?shapeBoundingBox 100.00 ?mirrored nil ?fullContact nil 
	?suppressUnconnectPads nil ?drawMissingPadApertures nil ?useApertureRotation nil 
	?suppressShapeFill nil ?vectorBasedPad t ?drawHolesOnly nil 
	?domains '(ipc2581 pdf artwork visibility ) ?ipc2581 '() 
	?layers '("VIA CLASS/SOLDERMASK_TOP" "PIN/SOLDERMASK_TOP" "PACKAGE GEOMETRY/SOLDERMASK_TOP" "BOARD GEOMETRY/SOLDERMASK_TOP" "BOARD GEOMETRY/DESIGN_OUTLINE" ))
axlFilmCreate( "PASTEMASK_BOTTOM" ?negative nil ?undefineLineWidth 6.00 ?sequence 4 
	?rotation 0 ?xOffset 0.00 ?yOffset 0.00 ?shapeBoundingBox 100.00 ?mirrored nil ?fullContact nil 
	?suppressUnconnectPads nil ?drawMissingPadApertures nil ?useApertureRotation nil 
	?suppressShapeFill nil ?vectorBasedPad t ?drawHolesOnly nil 
	?domains '(ipc2581 pdf artwork visibility ) ?ipc2581 '() 
	?layers '("PIN/PASTEMASK_BOTTOM" "BOARD GEOMETRY/DESIGN_OUTLINE" ))
axlFilmCreate( "PASTEMASK_TOP" ?negative nil ?undefineLineWidth 6.00 ?sequence 3 
	?rotation 0 ?xOffset 0.00 ?yOffset 0.00 ?shapeBoundingBox 100.00 ?mirrored nil ?fullContact nil 
	?suppressUnconnectPads nil ?drawMissingPadApertures nil ?useApertureRotation nil 
	?suppressShapeFill nil ?vectorBasedPad t ?drawHolesOnly nil 
	?domains '(ipc2581 pdf artwork visibility ) ?ipc2581 '() 
	?layers '("PIN/PASTEMASK_TOP" "BOARD GEOMETRY/DESIGN_OUTLINE" ))
axlFilmCreate( "BOTTOM" ?negative nil ?undefineLineWidth 6.00 ?sequence 2 
	?rotation 0 ?xOffset 0.00 ?yOffset 0.00 ?shapeBoundingBox 100.00 ?mirrored nil ?fullContact nil 
	?suppressUnconnectPads nil ?drawMissingPadApertures nil ?useApertureRotation nil 
	?suppressShapeFill nil ?vectorBasedPad t ?drawHolesOnly nil 
	?domains '(ipc2581 pdf artwork visibility ) ?ipc2581 '() 
	?layers '("BOARD GEOMETRY/DESIGN_OUTLINE" "ETCH/BOTTOM" "PIN/BOTTOM" "VIA CLASS/BOTTOM" ))
axlFilmCreate( "TOP" ?negative nil ?undefineLineWidth 6.00 ?sequence 1 
	?rotation 0 ?xOffset 0.00 ?yOffset 0.00 ?shapeBoundingBox 100.00 ?mirrored nil ?fullContact nil 
	?suppressUnconnectPads nil ?drawMissingPadApertures nil ?useApertureRotation nil 
	?suppressShapeFill nil ?vectorBasedPad t ?drawHolesOnly nil 
	?domains '(ipc2581 pdf artwork visibility ) ?ipc2581 '() 
	?layers '("BOARD GEOMETRY/DESIGN_OUTLINE" "ETCH/TOP" "PIN/TOP" "VIA CLASS/TOP" ))

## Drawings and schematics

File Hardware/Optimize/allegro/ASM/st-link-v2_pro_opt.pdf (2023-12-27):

# ART FILM - PDF_A_TOP

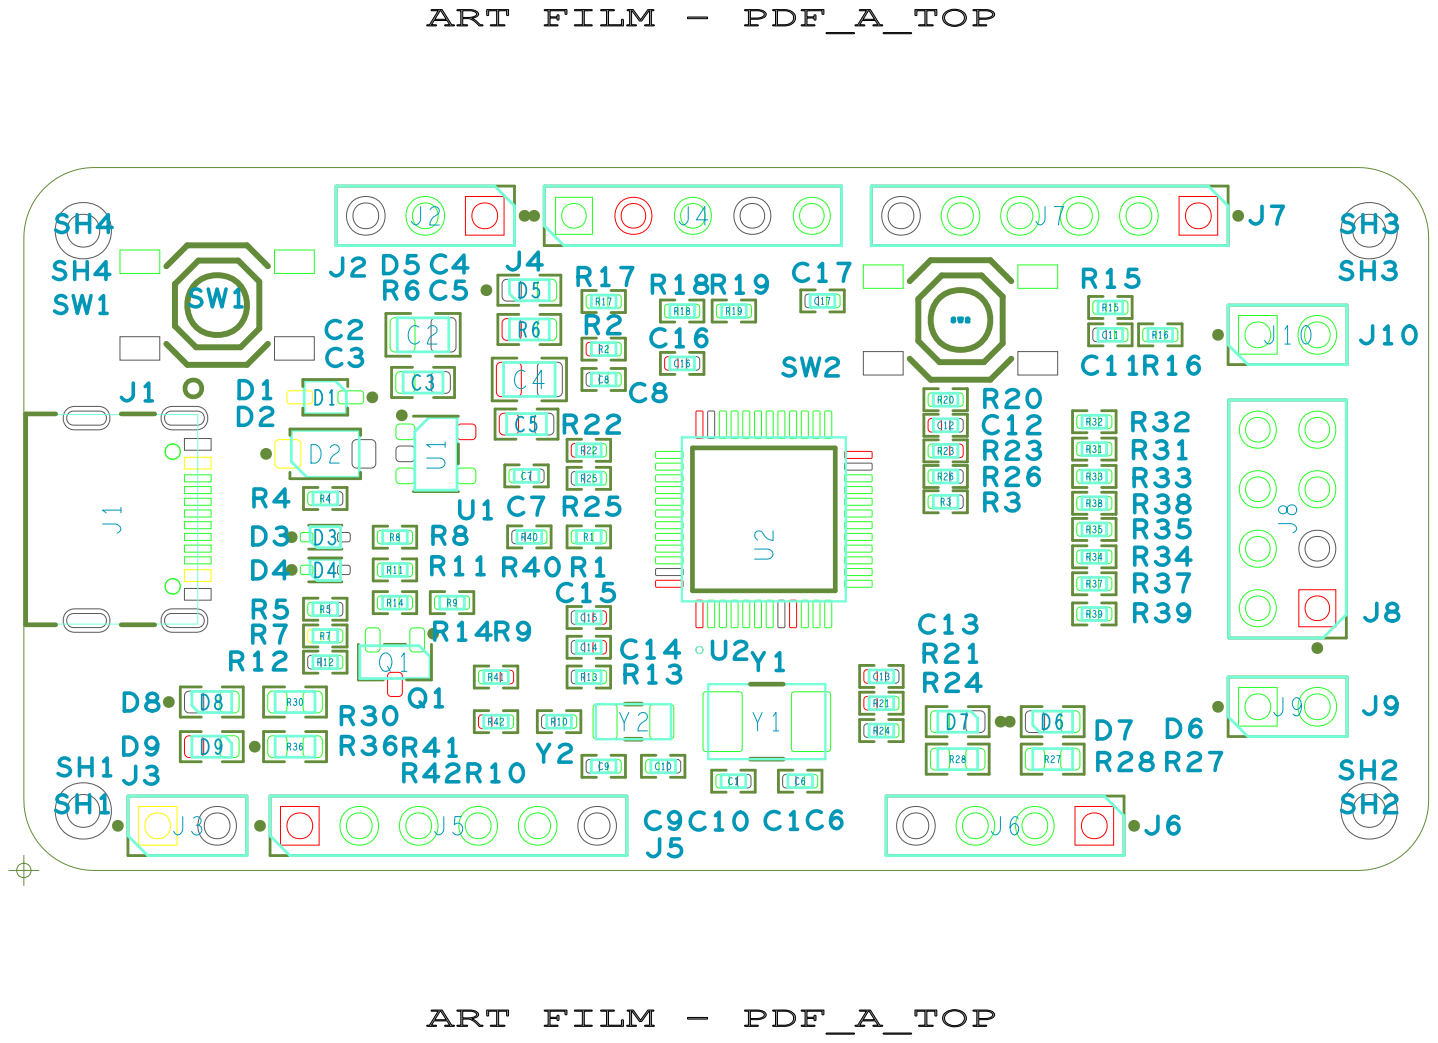
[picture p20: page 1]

# ART FILM - PDF_A_BOTTOM

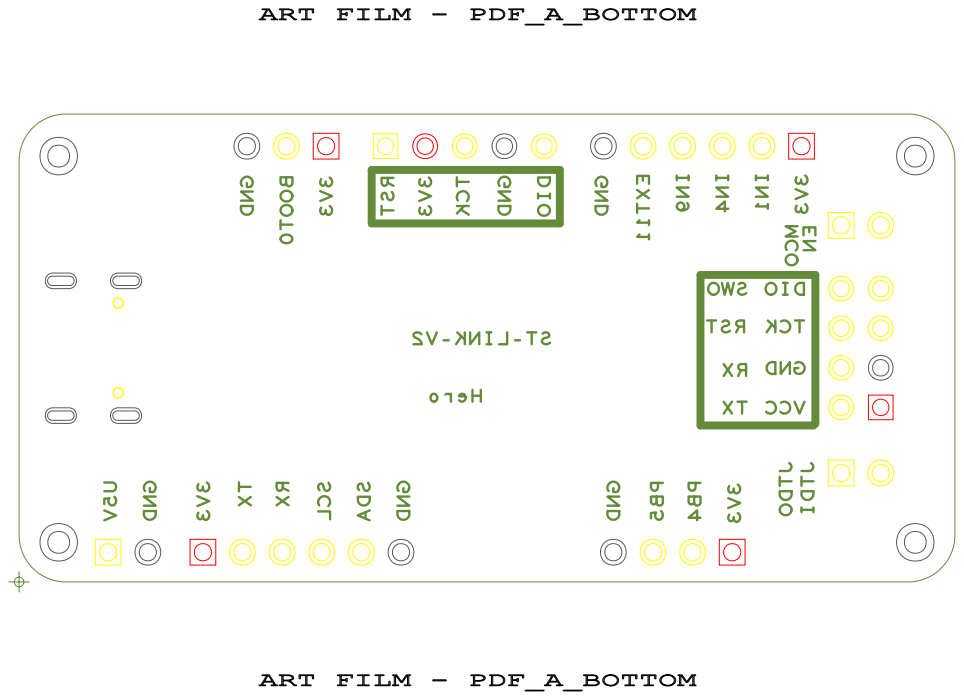
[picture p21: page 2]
ART FILM - PDF_A_BOTTOM; GND; BOOT0; SCL; SDA; RST; TCK; DIO; EXT11; JTDO; JTDI VCC

# ART FILM - ASSEMBLY_TOP

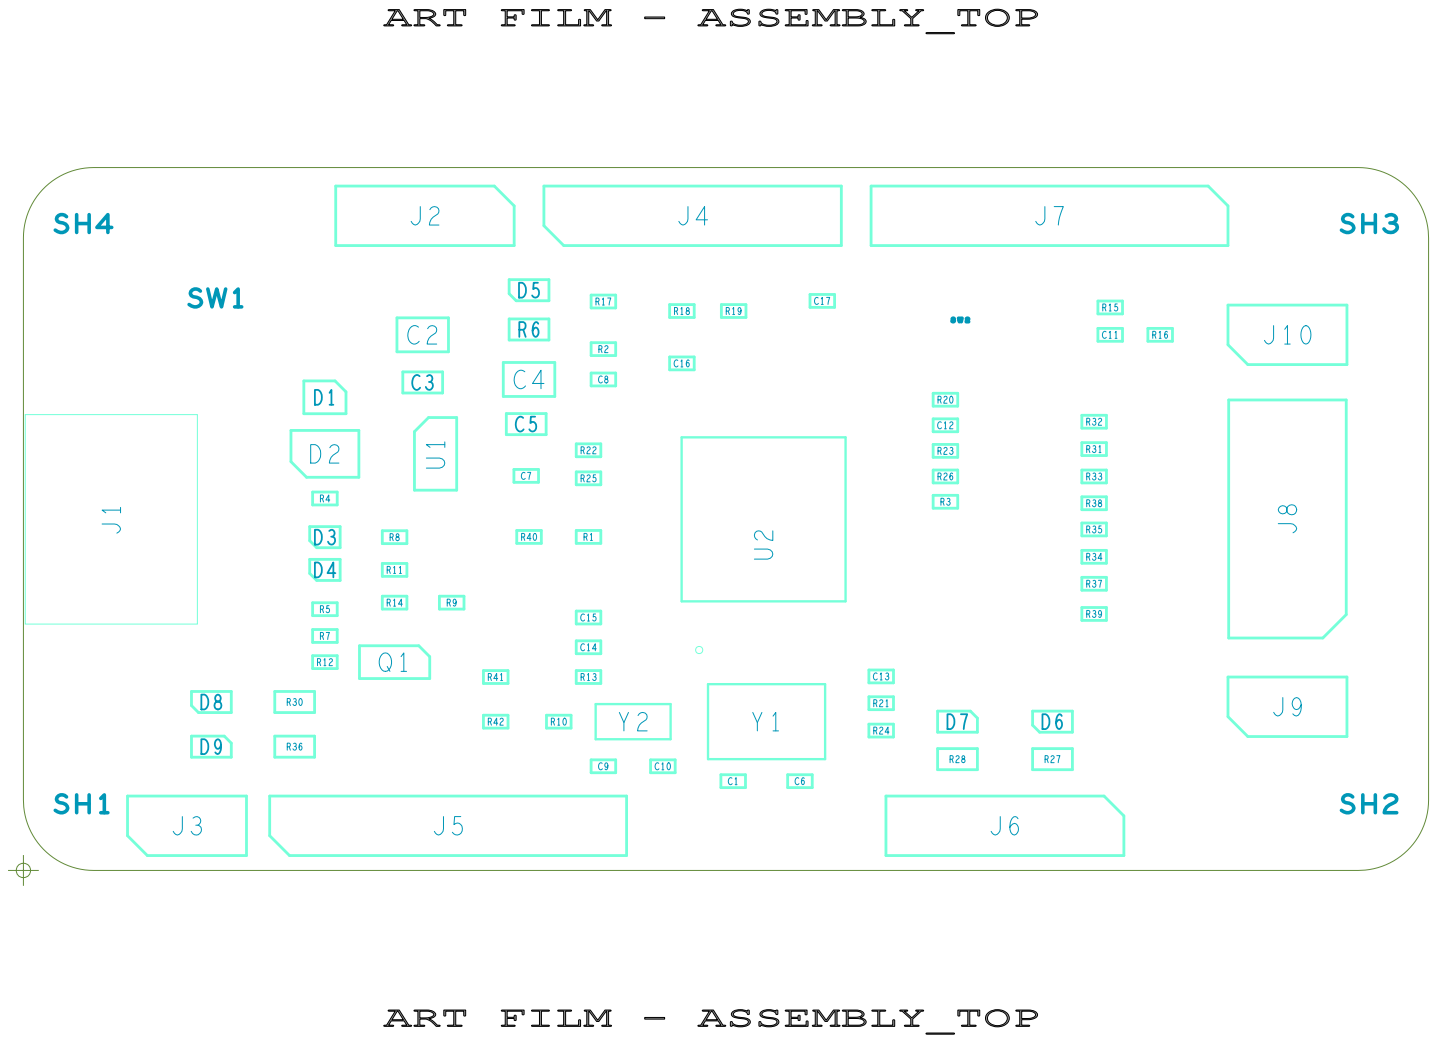
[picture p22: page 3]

# ART FILM - ASSEMBLY_BOTTOM

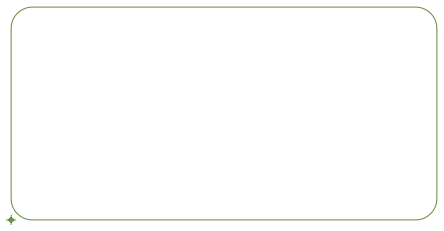
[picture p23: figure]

# ART FILM - ASSEMBLY_BOTTOM

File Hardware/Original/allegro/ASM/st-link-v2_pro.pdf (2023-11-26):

## ART FILM - PDF_A_TOP

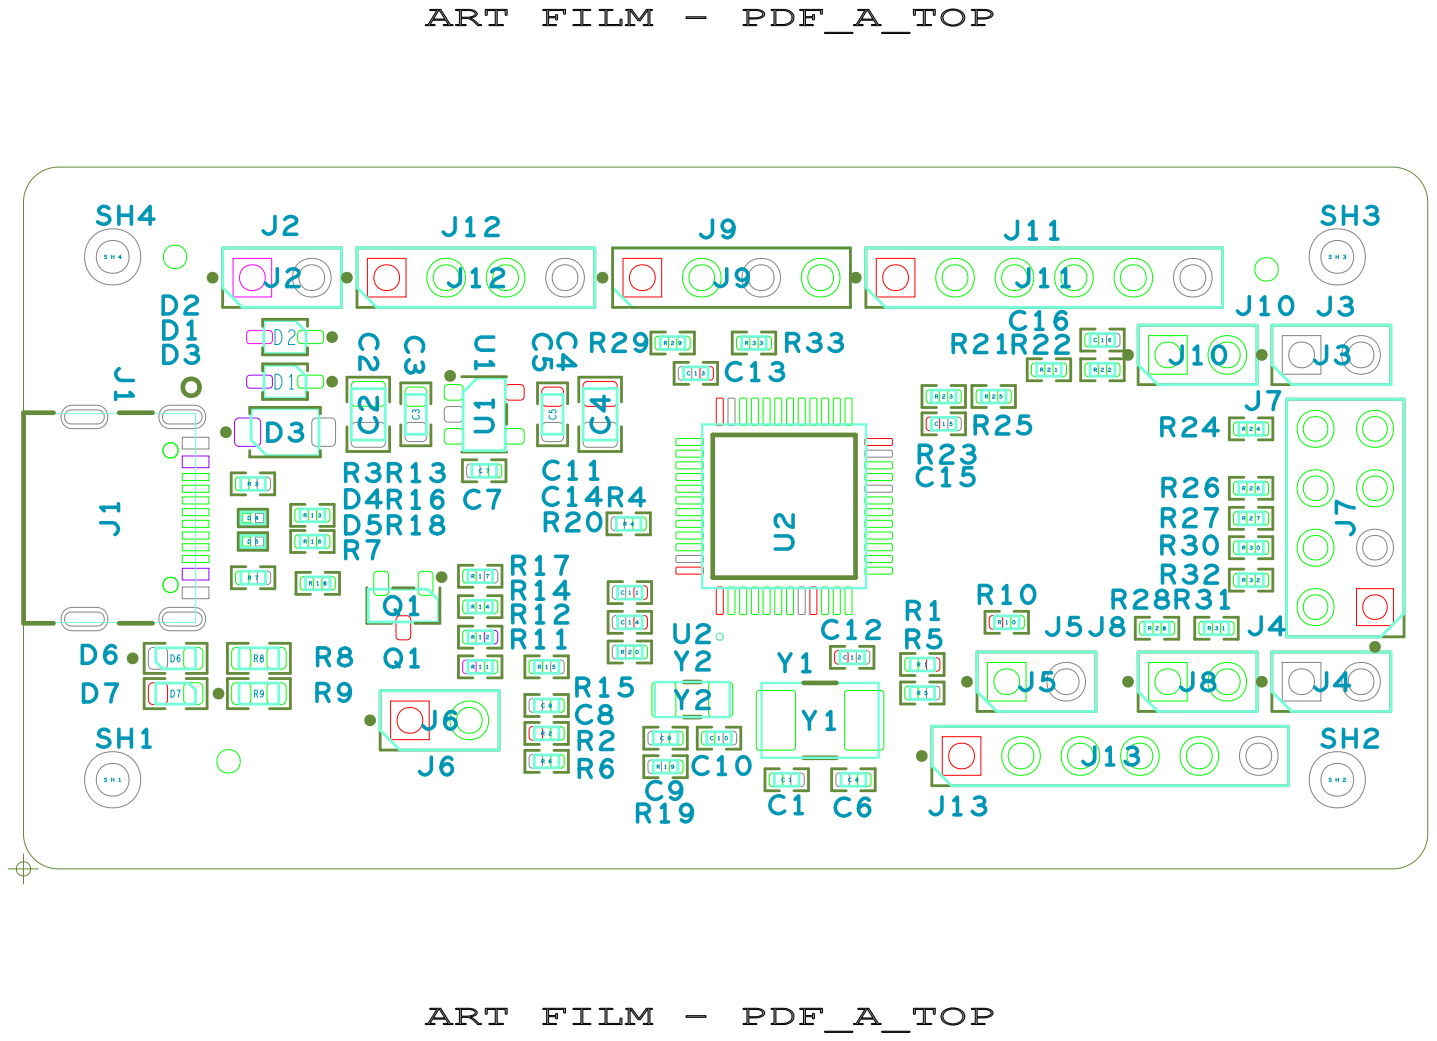
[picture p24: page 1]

## ART FILM - PDF_A_BOTTOM

# RST SDA GND

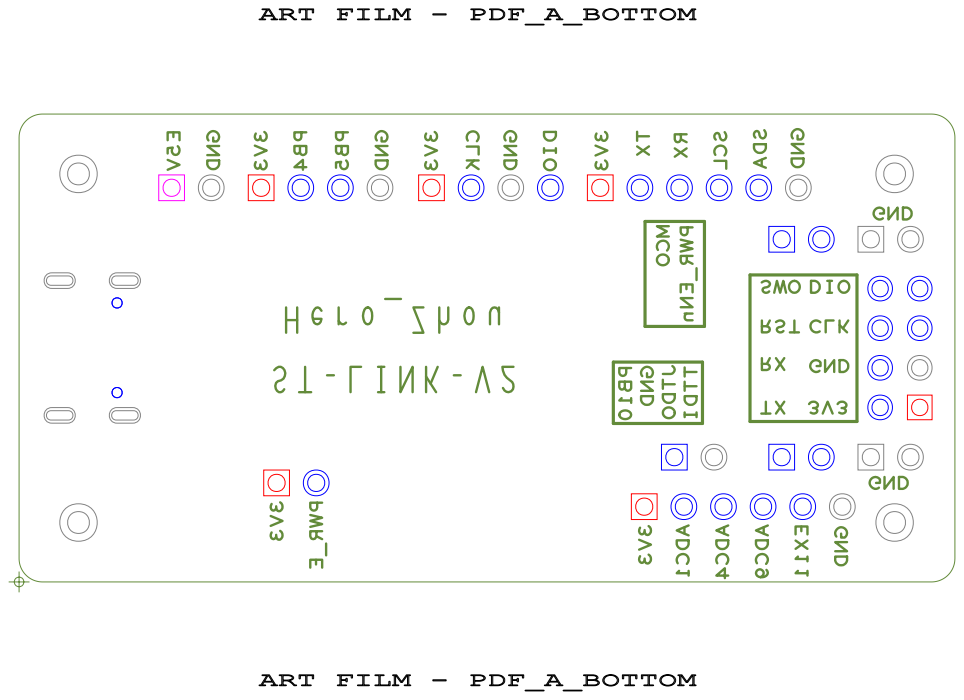
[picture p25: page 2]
ART FILM - PDF_A_BOTTOM; GND; PWR_E; ST-LINK-V2; Hero_Zhou PB4; CLK; DIO; ADC1; ADC4; JTDO; TTDI; MCO; PWR_ENn RX; SCL; ADC9; SWO

## ART FILM - ASSEMBLY_TOP

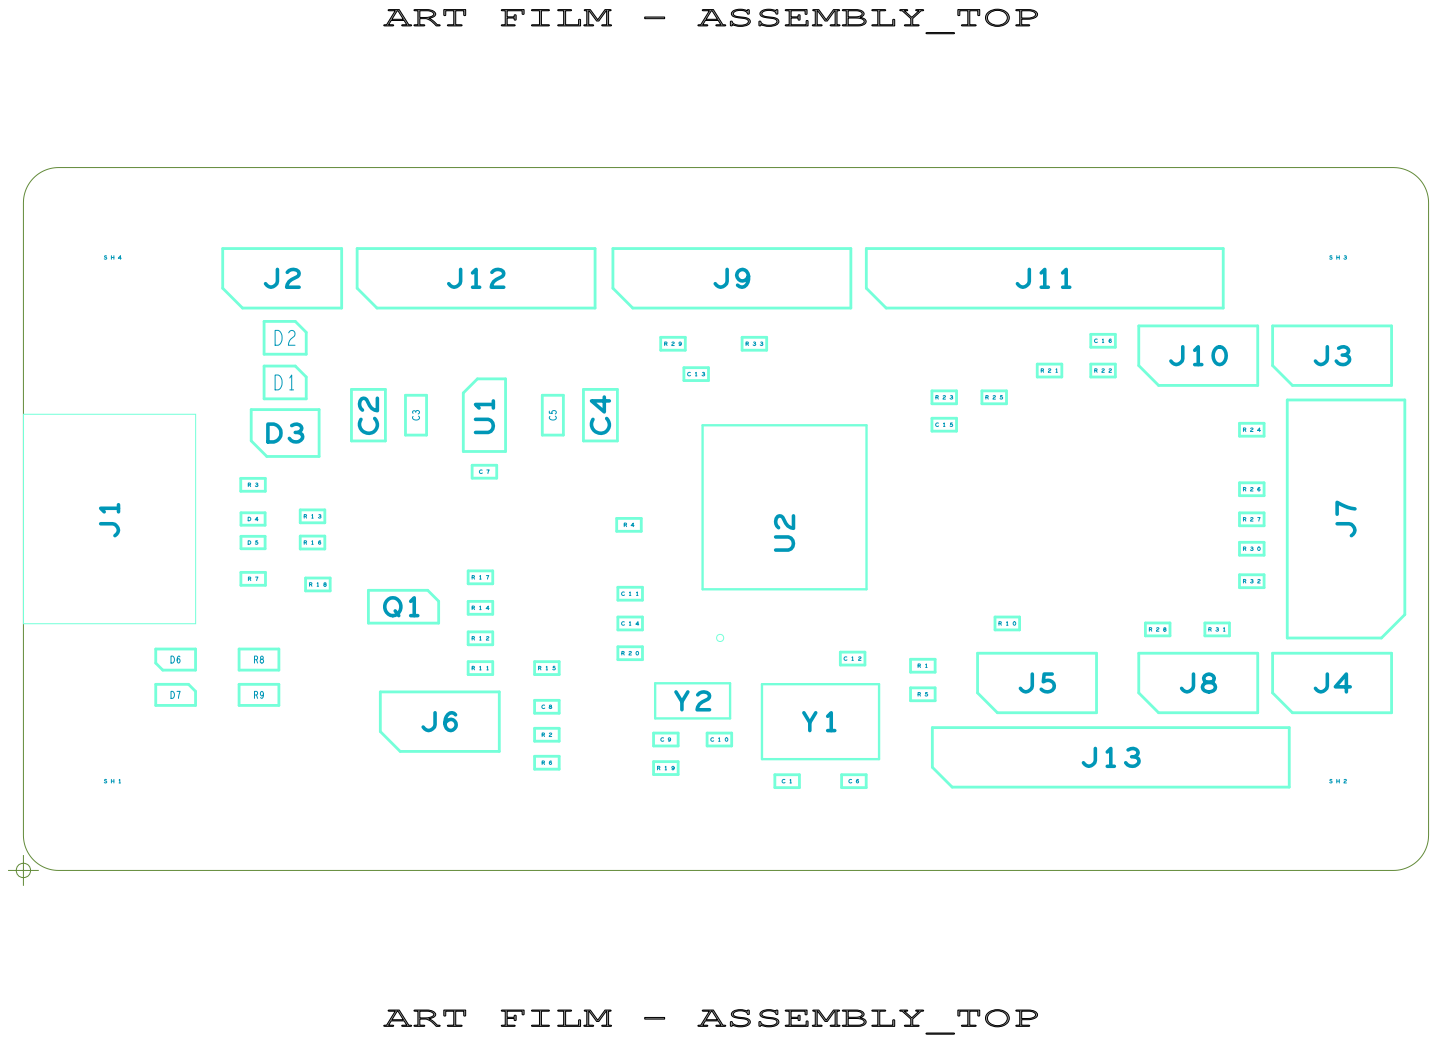
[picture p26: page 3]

## ART FILM - ASSEMBLY_BOTTOM

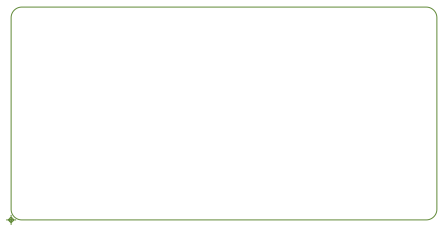
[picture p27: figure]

## ART FILM - ASSEMBLY_BOTTOM

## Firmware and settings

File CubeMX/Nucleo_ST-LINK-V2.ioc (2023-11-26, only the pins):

Mcu.UserName=STM32F103CBTx
PA0-WKUP.GPIO_Label=AIN_1
PA0-WKUP.Signal=ADCx_IN0
PA1.Signal=ADCx_IN1
PA10.GPIO_Label=T_SWO
PA10.Signal=GPIO_Output
PA11.Signal=USB_DM
PA12.Signal=USB_DP
PA13.Signal=SYS_JTMS-SWDIO
PA14.Signal=SYS_JTCK-SWCLK
PA15.GPIO_Label=USB_RENUMn
PA15.Signal=GPIO_Output
PA2.GPIO_Label=STLINK_TX
PA2.Signal=USART2_TX
PA3.GPIO_Label=STLINK_RX
PA3.Signal=USART2_RX
PA4.Signal=ADCx_IN4
PA5.GPIO_Label=T_JTCK
PA5.Signal=GPIO_Output
PA6.GPIO_Label=T_JTDO
PA6.Signal=GPIO_Output
PA7.GPIO_Label=T_JTDI
PA7.Signal=GPIO_Input
PA8.GPIO_Label=MCO
PA8.Signal=RCC_MCO
PA9.Signal=GPIO_Output
PB0.GPIO_Label=T_JRST
PB0.Signal=GPIO_Output
PB1.Signal=ADCx_IN9
PB10.GPIO_Label=RESERVED
PB10.Signal=GPIO_Input
PB11.Signal=GPXTI11
PB12.GPIO_Label=T_SWDIO_IN
PB12.Signal=GPIO_Input
PB13.GPIO_Label=T_JTCK
PB13.Signal=GPIO_Output
PB14.GPIO_Label=T_JTMS
PB14.Signal=GPIO_Output
PB15.GPIO_Label=PWR_ENn
PB15.Signal=GPIO_Output
PB2.Signal=GPIO_Input
PB3.GPIO_Label=PWR_EXT
PB3.Signal=GPIO_Input
PB4.Signal=GPIO_Output
PB5.Signal=GPIO_Output
PB6.Signal=USART1_TX
PB7.Signal=USART1_RX
PB8.Signal=I2C1_SCL
PB9.Signal=I2C1_SDA
PC13-TAMPER-RTC.GPIO_Label=Board_Ident
PC13-TAMPER-RTC.Signal=GPIO_Input
PC14-OSC32_IN.Signal=RCC_OSC32_IN
PC15-OSC32_OUT.Signal=RCC_OSC32_OUT
PD0-OSC_IN.Signal=RCC_OSC_IN
PD1-OSC_OUT.Signal=RCC_OSC_OUT

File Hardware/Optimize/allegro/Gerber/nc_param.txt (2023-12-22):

INTEGER-PLACES         5
DECIMAL-PLACES         5
X-OFFSET               0.000000
Y-OFFSET               0.000000
FEEDRATE               1
COORDINATES            ABSOLUTE
OUTPUT-UNITS           ENGLISH
TOOL-ORDER             INCREASING
REPEAT-CODES           NO
SUPPRESS-LEAD-ZEROES   YES
SUPPRESS-TRAIL-ZEROES  NO
SUPPRESS-EQUAL         NO
TOOL-SELECT            YES
OPTIMIZE_DRILLING      YES
ENHANCED_EXCELLON      YES
HEADER                 none
LEADER                 12
CODE                   ASCII
SEPARATE               NO
SEPARATE-ROUTING       NO
DRILLING               LAYER-PAIR
BACKDRILL              NO
CAVITY                 NO
COUNTER                NO
TOLERANCE_DRILL        YES
TOLERANCE_TRAVEL       YES
TOOL_SIZE              YES
ROTATION               YES
NON_STANDARD           YES
TOTAL_DRILL            NO
SEPARATE_SLOT          NO
SUPPRESS_TOLERANCE     YES
SUPPRESS_TOOLSIZE      YES
SUPPRESS_ROTATION      YES

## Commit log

2023-11-26 完成设计及相关文件输出
    [NUCLEO_ST-LINK-V2.DSN, ST-LINK-V2.DSN, ST-LINK-V2_PRO.DSN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]
2023-11-26 修改为立式8P连接器
    [ST-LINK-V2_PRO.DSN, ST-LINK-V2_PRO_BOM.xlsx, pdf_out_config.txt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]
2023-11-26 更新Gerber文件和嘉立创版BOM清单
    [BOM材料清单-嘉立创.xlsx, art_param.txt, nc_param.txt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]
2023-12-06 feat：固件烧录
    1、更新README文件
    2、增加烧录工具和bin文件
    3、实现了CDP，但是烧录功能有问题，待排查。
    [HQBrdTmp-1-2.drl]
2023-12-07 feat: 增加文档说明
    1、增加ST-LINK-V2-1说明
2023-12-09 feat:新建优化版原理图
    1、增加复位按键
    [BOM材料清单-嘉立创.xlsx, NUCLEO_ST-LINK-V2.DSN, ST-LINK-V2.DSN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]
2023-12-10 feat:未进行我知道的变更
2023-12-12 feat：优化ST-LINK-V2-1设计
    1、系统分析原理；
    2、去掉了不必要的器件；
    3、新增了板载LED和按键
    [ST-LINK-V2_PRO_OPT.DSN, cases.cfg, st-link-v2_pro_opt.xlsx]
2023-12-13 feat:新增DXF文件
    1、手动画了DXF文件
    2、重新开始了布局
    [ST-LINK-V2-1.dwg, ST-LINK-V2-1.dxf, ST-LINK-V2_PRO_OPT.DSN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]
2023-12-14 feat:完成优化版的初步布局
    [st-link-v2_pro_opt.brd]
2023-12-17 feat:完成大部分的布局和布线
    [st-link-v2_pro_opt.brd]
2023-12-18 feat:更新间距规则。
    [ST-LINK-V2_PRO_OPT.DSN, st-link-v2_pro_opt.brd]
2023-12-18 feat:完成优化版布局布线。
    [st-link-v2_pro_opt.brd]
2023-12-19 feat： 进行走线微调。
    [st-link-v2_pro_opt.brd]
2023-12-21 feat:开始进行丝印排版
    [st-link-v2_pro_opt.brd]
2023-12-22 feat:完成丝印摆放，但镜像错了
    [art_param.txt, nc_param.txt, st-link-v2_pro_opt.brd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]
2023-12-27 feat:完成优化版文件归档
    [BOM材料清单-嘉立创 常用备料.xlsx, BOM材料清单-嘉立创.xlsx, ST-LINK-V2-PRO_OPT.xlsx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]
2023-12-28 feat: 新增开发板功能测试示例代码。
